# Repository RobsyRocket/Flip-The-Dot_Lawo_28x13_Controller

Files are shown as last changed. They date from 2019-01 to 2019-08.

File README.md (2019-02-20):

# Flip-The-Dot Lawo 28x13 Controller
PCB to carry an FP2800a IC and connect it with a microcontroller of your choice to a flip-dot matrix with a 28x13 resolution made by Lawo.

More [details about the actual hardware](https://github.com/RobsyRocket/Flip-The-Dot/tree/master/Documentation/Hardware/Display%20-%20Lawo%2028x13) and software to drive it can be found in the repository of the parent project called [Flip-The-Dot](https://github.com/RobsyRocket/Flip-The-Dot).

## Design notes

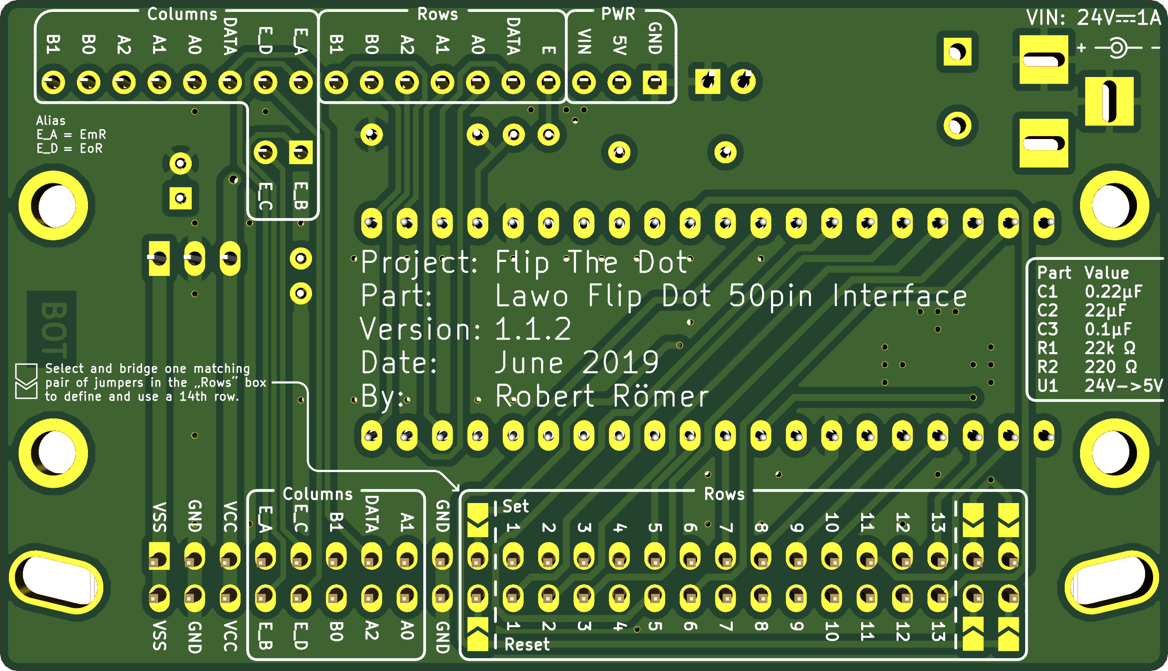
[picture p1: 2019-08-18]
Plots/Image/Bottom.png

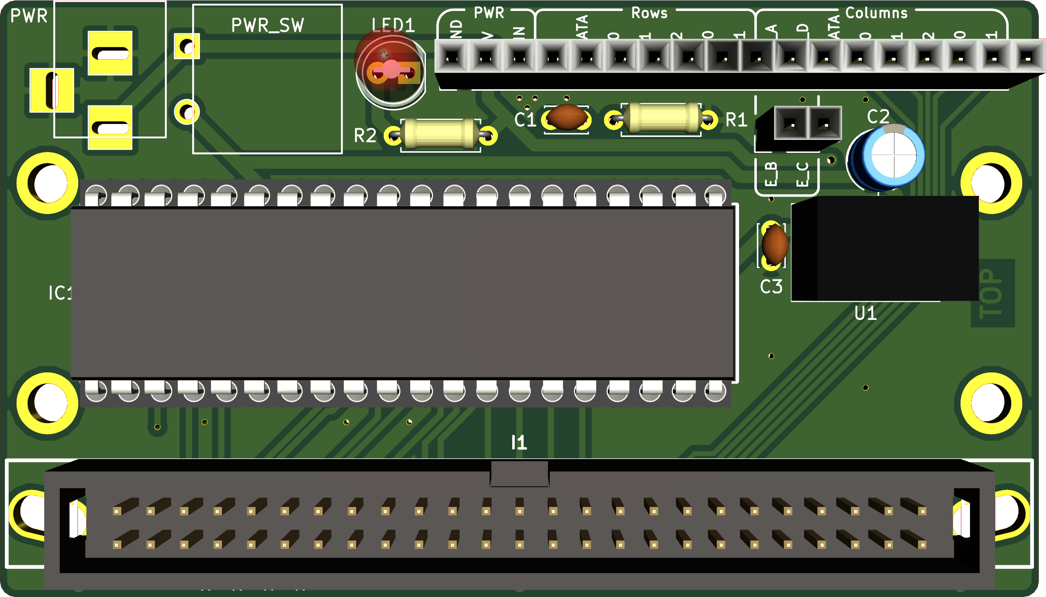
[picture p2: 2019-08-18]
Plots/Image/Top.png

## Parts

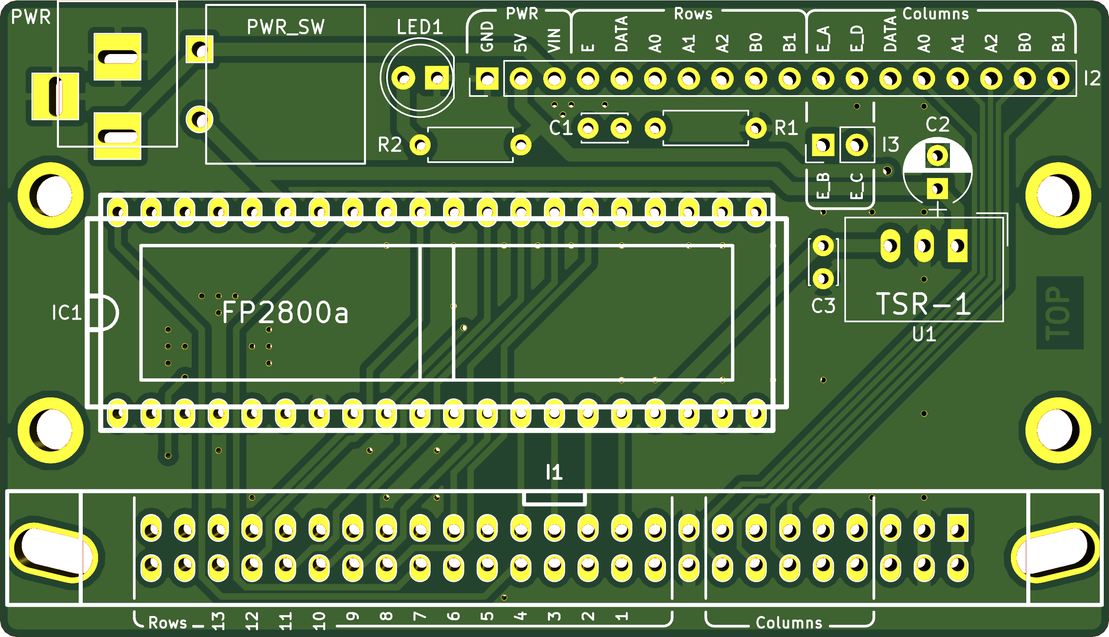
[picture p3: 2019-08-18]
Plots/Image/Top - without parts.png

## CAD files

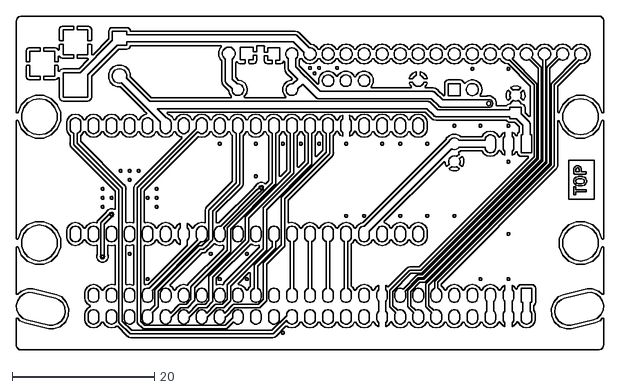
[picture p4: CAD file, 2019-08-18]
Plots/DXF/Lawo 28x13 Interface-F.Cu.dxf
82.7 x 47.0

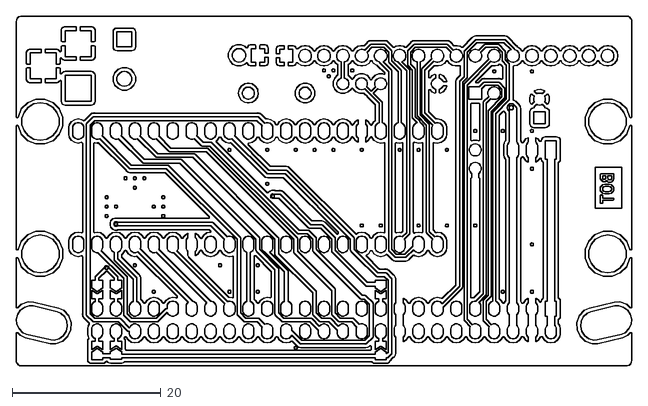
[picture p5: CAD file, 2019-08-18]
Plots/DXF/Lawo 28x13 Interface-B.Cu.dxf
82.7 x 47.0

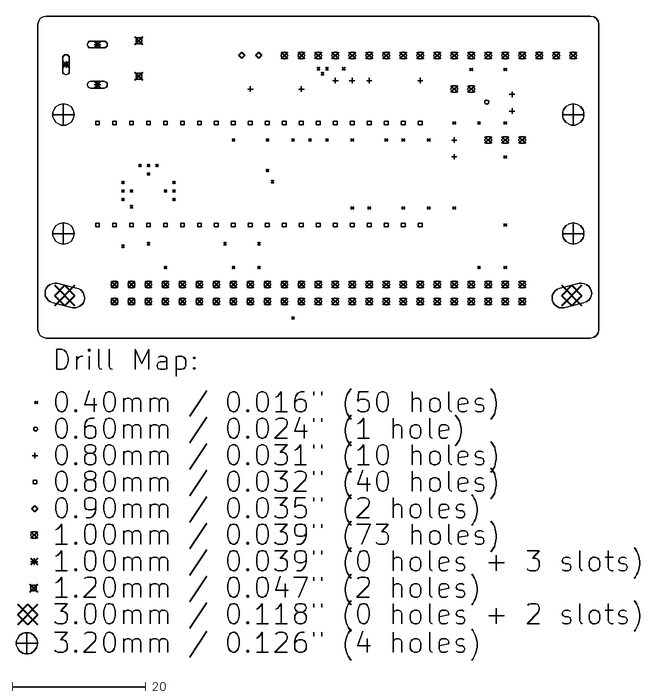
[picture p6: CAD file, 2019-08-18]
Plots/DXF/Lawo 28x13 Interface-PTH-drl_map.dxf
93.2 x 96.3

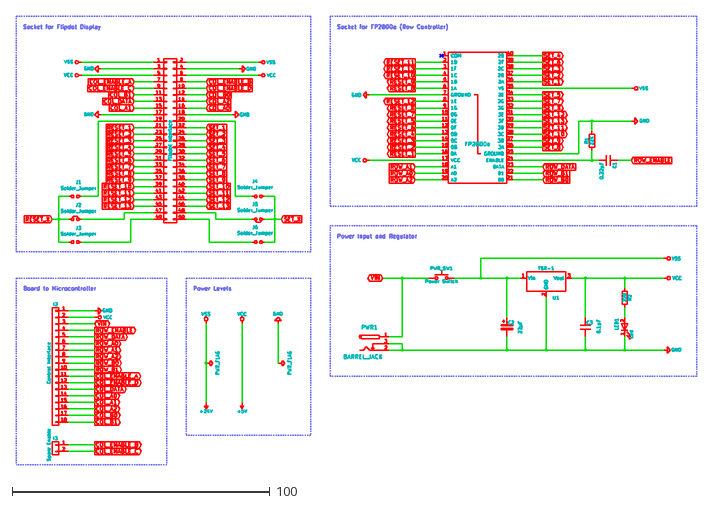
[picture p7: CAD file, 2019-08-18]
Plots/DXF/Lawo 28x13 Interface.dxf
264.2 x 174.0

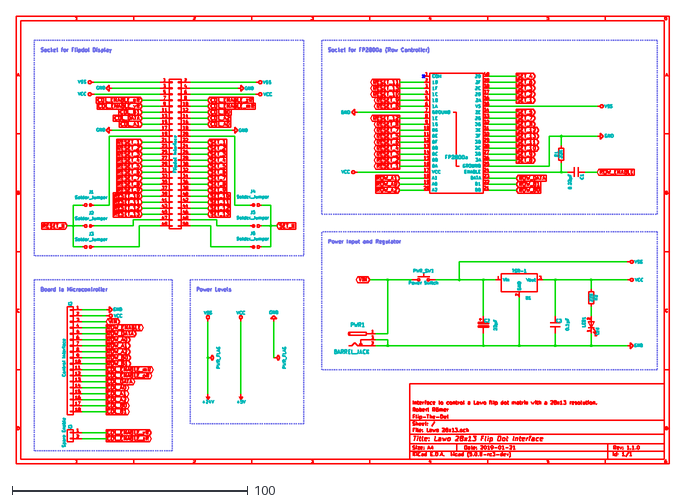
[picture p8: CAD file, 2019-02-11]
Plots/DXF/Lawo 28x13 Interface-Schematic.dxf
277.0 x 190.0

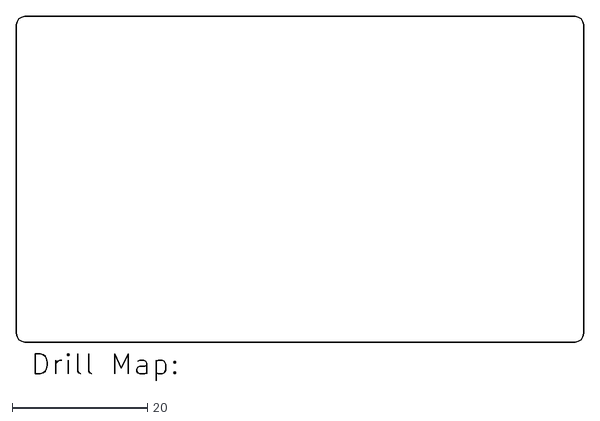
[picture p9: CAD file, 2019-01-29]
Plots/DXF/Lawo 28x13 Interface-NPTH-drl_map.dxf
83.8 x 53.8

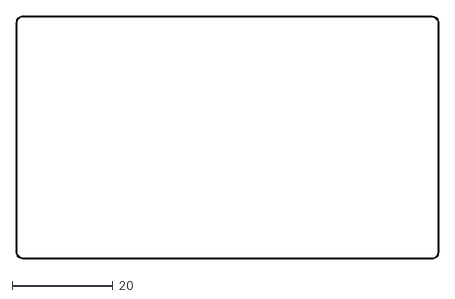
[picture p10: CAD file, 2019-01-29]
Plots/DXF/Lawo 28x13 Interface-Edge.Cuts.dxf
83.9 x 48.2

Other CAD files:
Plots/DXF/Lawo 28x13 Interface-B.Mask.dxf
Plots/DXF/Lawo 28x13 Interface-B.SilkS.dxf
Plots/DXF/Lawo 28x13 Interface-F.Mask.dxf
Plots/DXF/Lawo 28x13 Interface-F.SilkS.dxf

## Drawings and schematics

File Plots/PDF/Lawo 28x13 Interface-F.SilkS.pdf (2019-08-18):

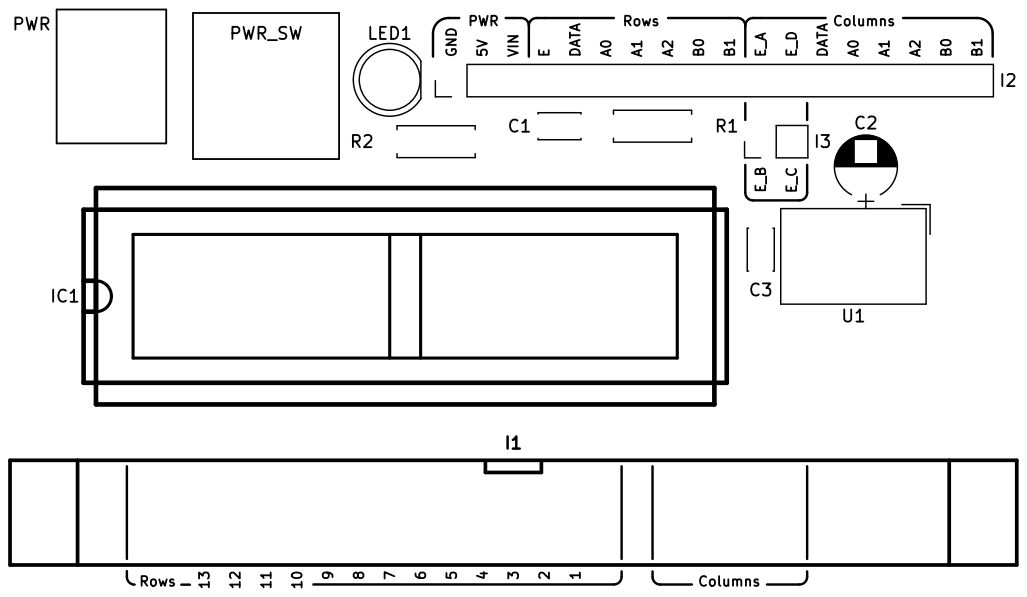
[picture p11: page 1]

113211710412 E_B E_C PWR PWR_SW A2 PWR Rows Columns GND 5VVIN

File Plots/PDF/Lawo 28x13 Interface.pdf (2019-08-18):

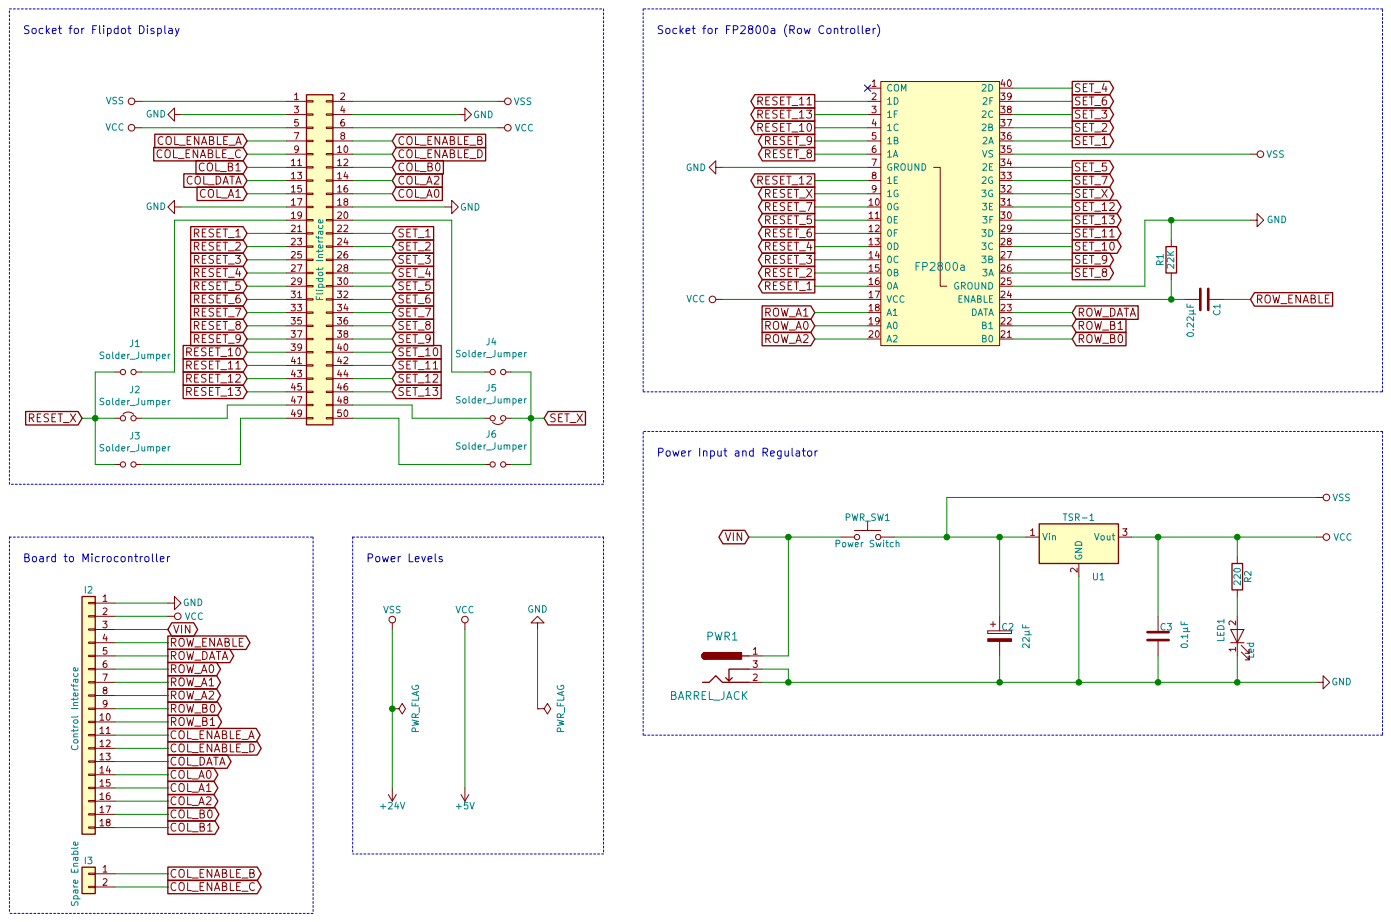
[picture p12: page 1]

Power Input and Regulator 1

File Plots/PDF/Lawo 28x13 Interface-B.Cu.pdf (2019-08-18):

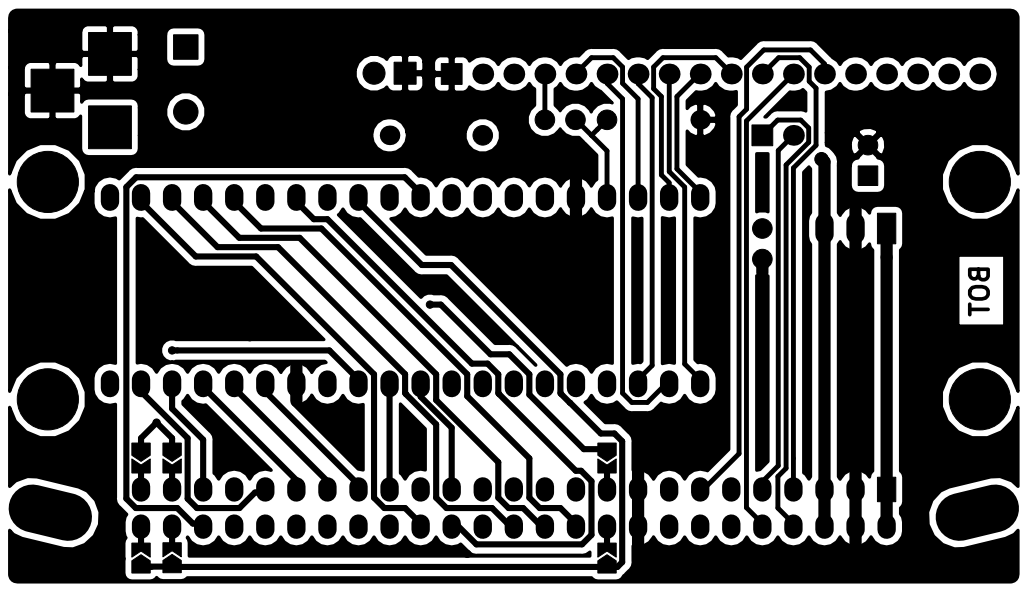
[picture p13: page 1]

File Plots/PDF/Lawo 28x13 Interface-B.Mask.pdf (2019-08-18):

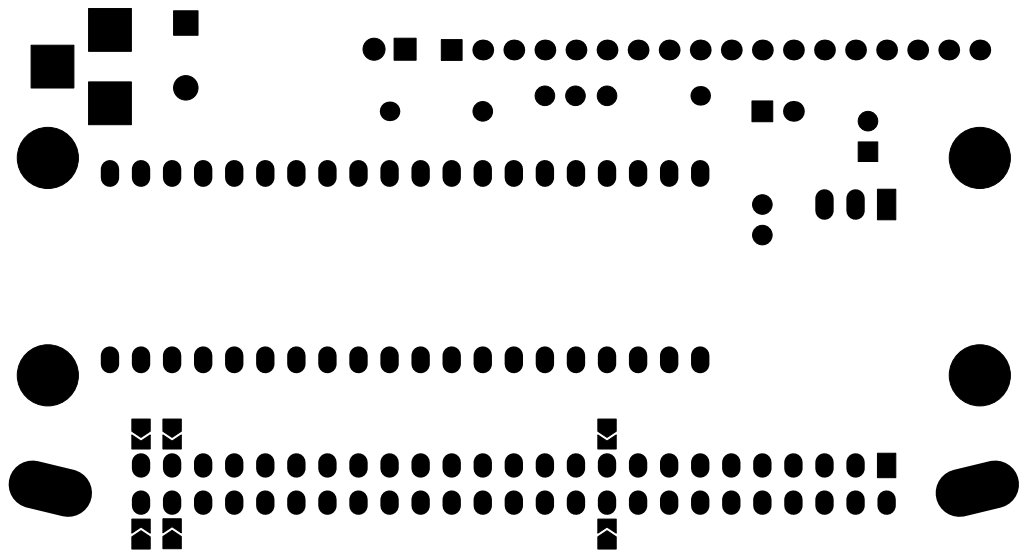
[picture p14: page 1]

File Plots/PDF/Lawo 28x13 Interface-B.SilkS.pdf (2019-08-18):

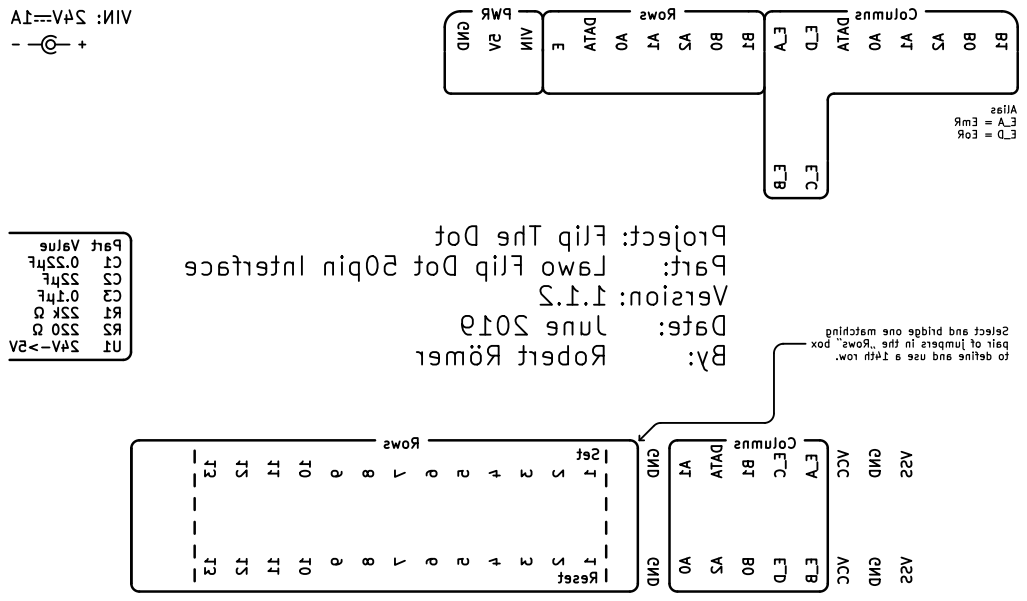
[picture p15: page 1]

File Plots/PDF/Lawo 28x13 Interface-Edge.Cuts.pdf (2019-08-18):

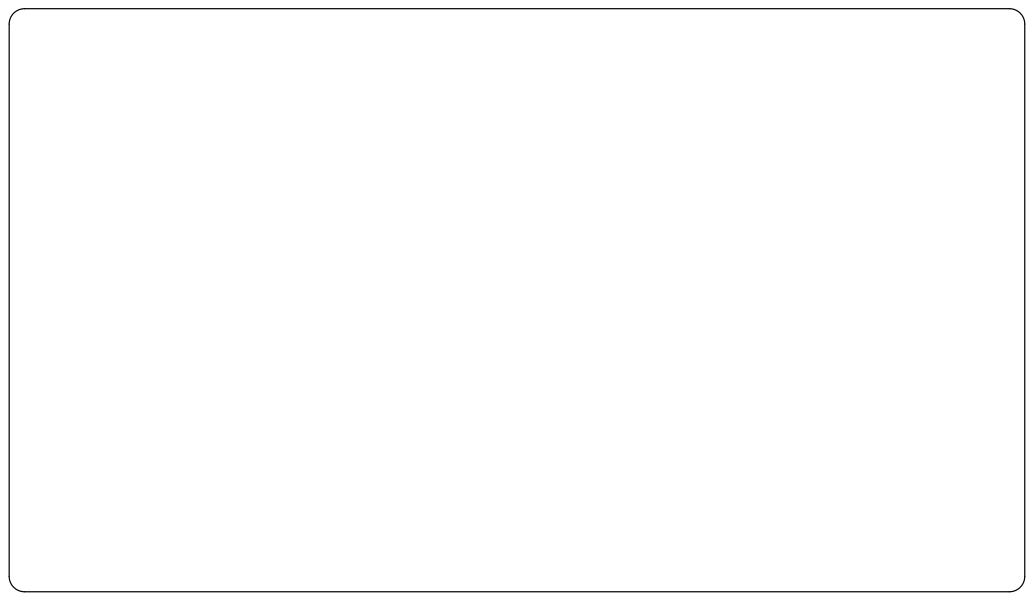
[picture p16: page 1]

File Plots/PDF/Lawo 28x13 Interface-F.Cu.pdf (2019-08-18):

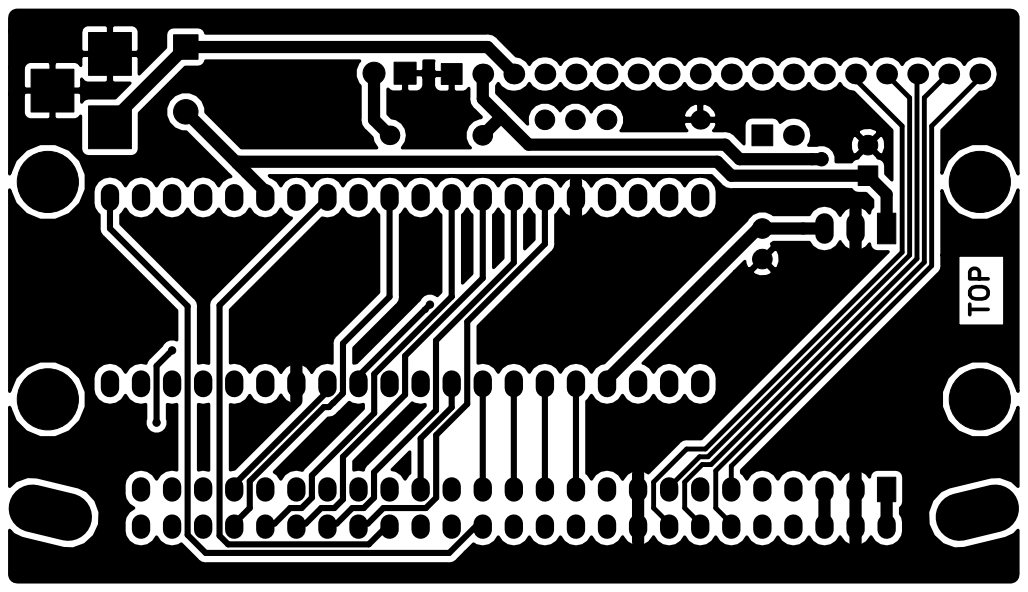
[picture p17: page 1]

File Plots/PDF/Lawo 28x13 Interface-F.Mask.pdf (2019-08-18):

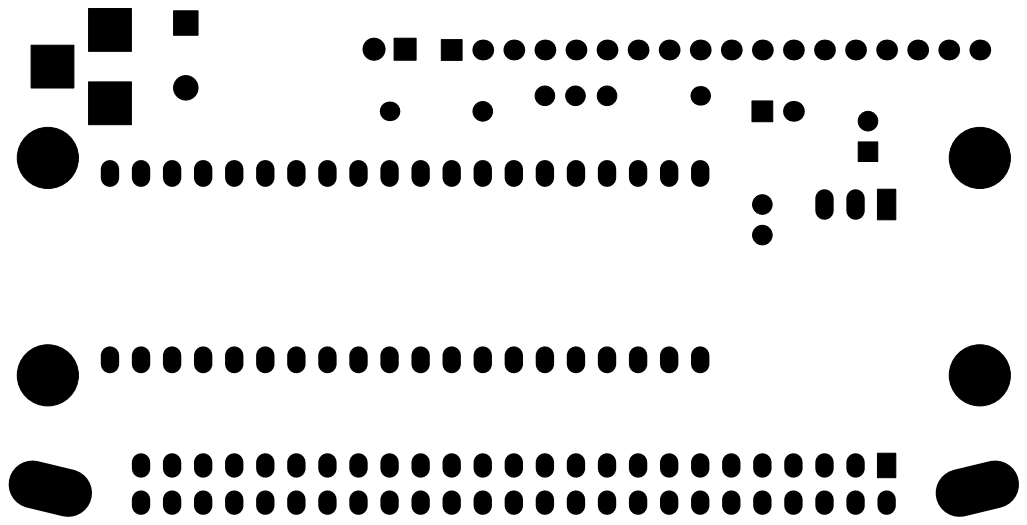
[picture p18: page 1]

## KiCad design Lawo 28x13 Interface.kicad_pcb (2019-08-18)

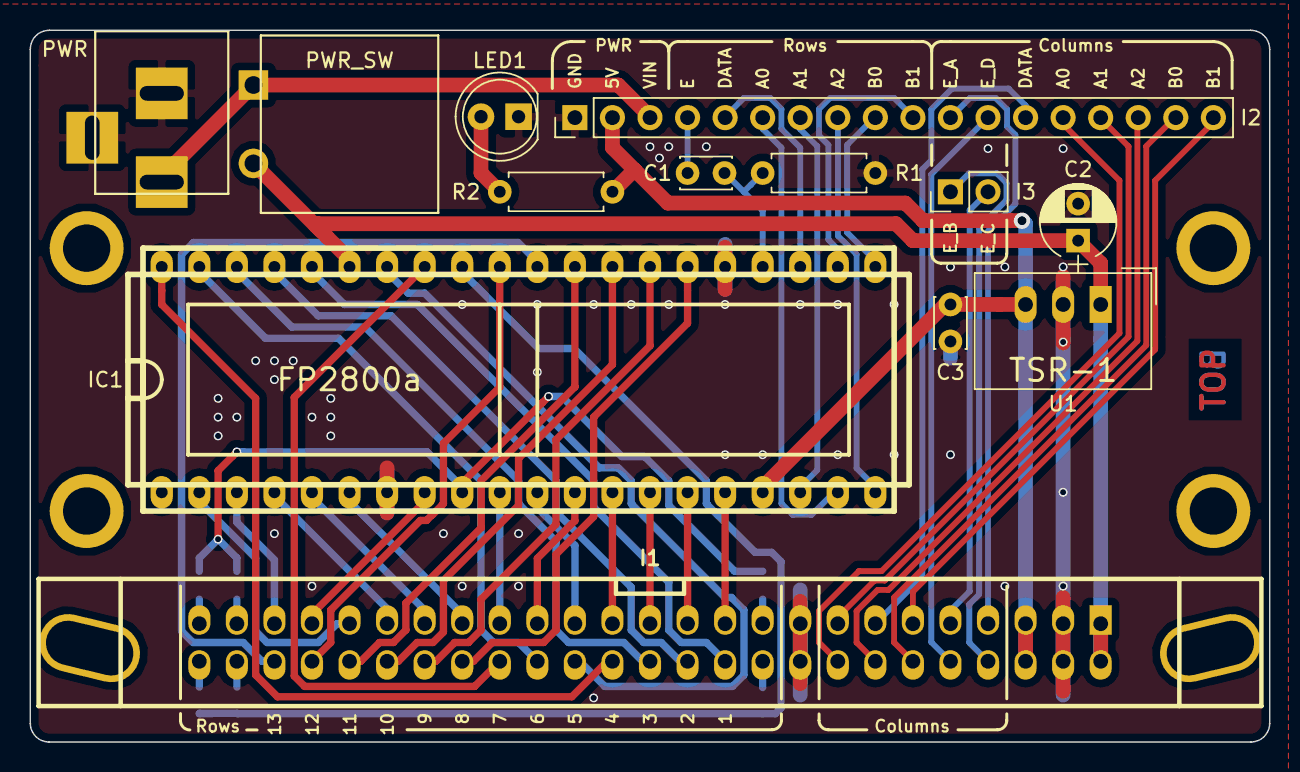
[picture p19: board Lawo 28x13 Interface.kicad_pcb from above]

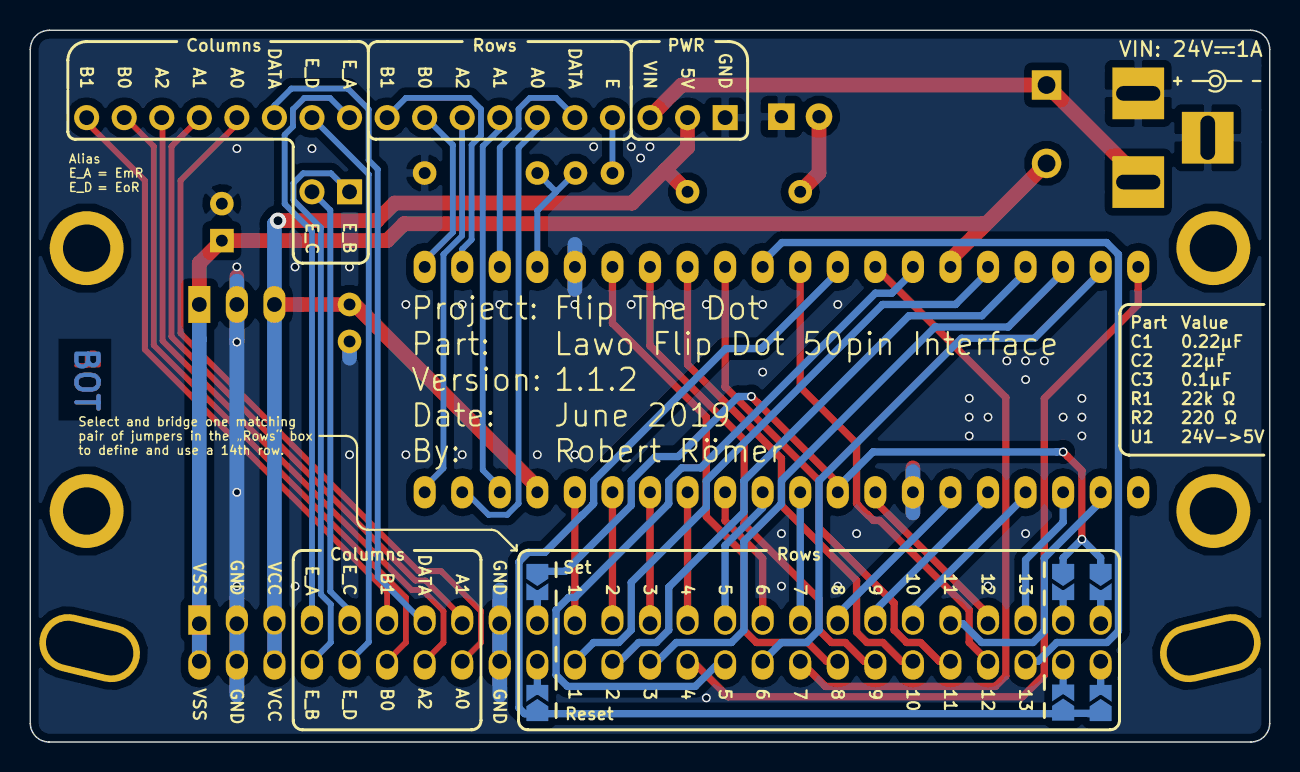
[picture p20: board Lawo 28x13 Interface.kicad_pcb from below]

Board: 2 copper layers, 83.8 x 48.1 mm, 23 parts (6 on the bottom side), 57 nets.

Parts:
C1: 0.22μF; C_Disc_D3.4mm_W2.1mm_P2.50mm
C2: 22μF; CP_Radial_D5.0mm_P2.50mm
C3: 0.1μF; C_Disc_D3.4mm_W2.1mm_P2.50mm
I1: Flipdot Interface; psl_50_25x2_strip_with_levers
I2: Control Interface; Socket_Strip_Straight_1x18_Pitch2.54mm
I3: Spare Enable; Socket_Strip_Straight_1x02_Pitch2.54mm
IC1: FP2800a; dil_40-600_socket
J1, J2, J3, J4, J5, J6: Solder_Jumper; SolderJumper-2_P1.3mm_Open_TrianglePad1.0x1.5mm
LED1: Led; LED_D5.0mm
MTH1, MTH2, MTH3, MTH4: 1pin
PWR1: BARREL_JACK
PWR_SW1: Power Switch; SW_PUSH
R1: 22K; R_Axial_DIN0207_L6.3mm_D2.5mm_P7.62mm_Horizontal
R2: 220; R_Axial_DIN0207_L6.3mm_D2.5mm_P7.62mm_Horizontal
U1: TSR-1; DCDC-Conv_TRACO_TSR-1

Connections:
+5V: C3.1, I1.5, I1.6, I2.2, IC1.17, R2.1, U1.3
+24V: C2.1, I1.1, I1.2, IC1.35, PWR_SW1.2, U1.1
COL_A0: I1.16, I2.14
COL_A1: I1.15, I2.15
COL_A2: I1.14, I2.16
COL_B0: I1.12, I2.17
COL_B1: I1.11, I2.18
COL_DATA: I1.13, I2.13
COL_ENABLE_A: I1.7, I2.11
COL_ENABLE_B: I1.8, I3.1
COL_ENABLE_C: I1.9, I3.2
COL_ENABLE_D: I1.10, I2.12
GND: C2.2, C3.2, I1.3, I1.4, I1.17, I1.18, I2.1, IC1.7, IC1.25, LED1.1, PWR1.2, PWR1.3, R1.2, U1.2
unnamed: C1.2, IC1.24, R1.1
unnamed: I1.19, J1.2
unnamed: I1.20, J4.2
unnamed: I1.47, J2.2
unnamed: I1.48, J5.2
unnamed: I1.49, J3.2
unnamed: I1.50, J6.2
unnamed: LED1.2, R2.2
RESET_1: I1.21, IC1.16
RESET_2: I1.23, IC1.15
RESET_3: I1.25, IC1.14
RESET_4: I1.27, IC1.13
RESET_5: I1.29, IC1.11
RESET_6: I1.31, IC1.12
RESET_7: I1.33, IC1.10
RESET_8: I1.35, IC1.6
RESET_9: I1.37, IC1.5
RESET_10: I1.39, IC1.4
RESET_11: I1.41, IC1.2
RESET_12: I1.43, IC1.8
RESET_13: I1.45, IC1.3
RESET_X: IC1.9, J1.1, J2.1, J3.1
ROW_A0: I2.6, IC1.19
ROW_A1: I2.7, IC1.18
ROW_A2: I2.8, IC1.20
ROW_B0: I2.9, IC1.21
ROW_B1: I2.10, IC1.22
ROW_DATA: I2.5, IC1.23
ROW_ENABLE: C1.1, I2.4
SET_1: I1.22, IC1.36
SET_2: I1.24, IC1.37
SET_3: I1.26, IC1.38
SET_4: I1.28, IC1.40
SET_5: I1.30, IC1.34
SET_6: I1.32, IC1.39
SET_7: I1.34, IC1.33
SET_8: I1.36, IC1.26
SET_9: I1.38, IC1.27
SET_10: I1.40, IC1.28
SET_11: I1.42, IC1.29
SET_12: I1.44, IC1.31
SET_13: I1.46, IC1.30
SET_X: IC1.32, J4.1, J5.1, J6.1
VIN: I2.3, PWR1.1, PWR_SW1.1

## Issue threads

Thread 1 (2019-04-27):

Validate placed capacitor types with need ones

RobsyRocket, 2019-04-27:
Check the data sheets of TSR-1 and FP2800a for which capacitor types and values are needed and if the correct ones including matching footprints are placed in the schematic and on the PCB. Especially validate as the usage between version 0.9 and 1.1.1 has changed.

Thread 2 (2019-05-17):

fix dependency path for FP2800a

RobsyRocket, 2019-05-17:
The include path of the custom KiCad library for the part FP2800a does not work without the parent project Flip-The-Dot.

To resolve this issue it is required to perform the following steps:
* [x] fixing https://github.com/RobsyRocket/Flip-The-Dot/issues/2 first
* [ ] adding the new repo of FP2800a as submodule
* [ ] adjusting the path in sym-lib-table

Closed 2019-05-24.

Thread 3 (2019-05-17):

Extend support for other Lawo modules with 50pin connectors

RobsyRocket, 2019-05-17:
Lawo seems to have made some more modules which share the same 50 pin connector and pretty similar signal mapping.

Know are at least the following kinds:
* Lawo 28x13
* Lawo 14x13
* Lawo 28x16

It should be checked which wiring updates and additional feature are needed to make this controller more versatile.

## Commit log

2019-01-29 initial commit of PCB files - Work In Progress
    - layout not fully verified
    - additional libraries not included
    [Lawo 28x13-B.Cu.dxf, Lawo 28x13-B.Mask.dxf, Lawo 28x13-B.SilkS.dxf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]
2019-02-11 Updated schematic for upgraded KiCad version and rework of many traces and pin assignments
    - KiCad version upgrade
    - EESchema Schematic File Version 4
    - KiCad 5.0.0-rc3-dev
    - symbols and footprint exchanged to newer versions
    - board changes
    - changed pin assignments for the set pins (swapped group of FP2800a 2a-g and 3a-g)
    - additional enable pins E_zR and E_yZ for spare connections
    - additional traces for one more set and one reset pin, routing to I1 selectable via solder jumper
    - increased trace widths
    - increased board size
    - silkscreen updates (outlines, component values, pin labels, ...)
    - bunch of vias added to shorten ground loops
    - updated plots of the upgraded schematic, i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
    [Lawo 28x13-B.Cu.dxf, Lawo 28x13-B.Mask.dxf, Lawo 28x13-B.SilkS.dxf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]
2019-04-26 Renaming of all files by changing "Lawo 28x13" to "Lawo 28x13 Interface" to clarify its use compared to the Lawo flip-dot module itself.
    [Lawo 28x13 Interface-B.Cu.dxf, Lawo 28x13 Interface-B.Mask.dxf, Lawo 28x13 Interface-B.SilkS.dxf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]
2019-04-26 minor PCB updates
    - mounting holes are not connected to GND anymore
    - one trace and some Vias moved a little bit
    - updated/added Silkscreen texts (outlines, parts legend and text related to TSR-1, EyR, and EzR)
    - updated plots for the PCB
    - new plots for the schematic and PCB images without rendered parts
    [Lawo 28x13 Interface-B.Cu.dxf, Lawo 28x13 Interface-B.SilkS.dxf, Lawo 28x13 Interface-F.Cu.dxf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]
2019-05-24 closes #2 by adding KiCad library for the FP2800a IC as git submodule and adjusting path in sym-lib-table
    additional changes:
    - removal of TSR-1 lib reference as it is not needed anymore, existing KiCad symbol already in use
    - removal of rescue lib reference as it is not used and not committed
2019-08-18 Renamed enable pins and slightly modified traces and silk screen.
    [Lawo 28x13 Interface-B.Cu.dxf, Lawo 28x13 Interface-B.Mask.dxf, Lawo 28x13 Interface-B.SilkS.dxf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]
